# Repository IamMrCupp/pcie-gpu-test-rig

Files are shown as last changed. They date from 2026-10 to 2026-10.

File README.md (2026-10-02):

# pcie-gpu-test-rig

A bench rig for powering a graphics card with no motherboard — a PCIe riser and the card's aux connectors, fed from a current-limited bench supply through a fused, switched, metered 12 V box. Put a dead card on it and in thirty seconds you know whether it draws nothing, idles like a healthy card, or drags the supply into current limit.

Wiring schematic, rev D

## What's here

| Path | What |
|---|---|
| [`wiring/pcie_rig_power.kicad_sch`](wiring/pcie_rig_power.kicad_sch) | The schematic. KiCad 10, ERC clean with every severity on — CI re-checks it on every push. |
| [`wiring/pcie_rig_power.pdf`](wiring/pcie_rig_power.pdf) · [`.svg`](wiring/pcie_rig_power.svg) · [`_bom.csv`](wiring/pcie_rig_power_bom.csv) | Renders and the parts list, all regenerated from the schematic with `kicad-cli`. CI fails if any is stale. |
| [`BOM.md`](BOM.md) | Everything you buy or print, with quantities, dimensions and sources. |
| [`BUILD.md`](BUILD.md) | The procedure: print, fit the panel parts, wire, close, make the leads, the continuity table, first power-up. |
| [`WIRING.md`](WIRING.md) | The electrical reference: wire-by-wire list keyed to the schematic's nets, why the two traps are traps, the lead recipes, limits. |

The printed enclosure — a 4×4 Clickfinity-footed box with the meter, switch, and probe post on the deck and a storage bin on top for the riser kit — lives in [3d-printer-models](https://github.com/IamMrCupp/3d-printer-models) as `pcie-rig-enclosure` ([in review](https://github.com/IamMrCupp/3d-printer-models/pull/165)), so it keeps the shared Gridfinity library and that repo's render checks. The wiring doesn't depend on it.

## How it works

**12 V IN → 8 A fuse → PZEM-031 meter → rocker → outputs.** Keyed XT60 for the riser and the card, banana pairs beside them for probing and plain-lead supplies, and a probe-ground post for the scope. The meter sits ahead of the switch, so you see 12.0 V on the box before you ever enable the card. Every join inside is a WAGO lever nut — no solder, no terminal with two wires on it.

**The protection is the bench supply, not the box.** Set it to 12.0 V, OVP 12.6 V, and a 6 A current limit — the rig's working ceiling. The fuse is a backstop. Everything else in the path is overrated on purpose.

> **Never feed this from an ATX or server supply** — anything that can deliver tens of amps into a shorted card will. A current-limited bench supply is the whole point.

## What it tells you

| Reading | Usual meaning |
|---|---|
| About 0 A | Rails aren't coming up. Check the enable chain, and see *Caveats*. |
| Roughly 1–2.5 A | The card is idling. |
| Supply drops into current limit | A short or a stuck phase. Switch off, then find it with injection and a thermal camera. |

The idle range is a starting point from other people's builds, not a spec. Build your own table from known-good cards.

## Two wiring traps

Both are in [`WIRING.md`](WIRING.md) and on the schematic sheet, and both fail silently:

- **The meter's shunt is in the negative leg**, between its terminals 2 and 1. Land the input negative on the ground bus instead of terminal 2 and the current bypasses the shunt — the meter reads 0.00 A forever and a working card looks dead.
- **The rocker's load and LED pins must not swap.** Put the load on the LED pin and ground on the load pin, and the first flick is a dead short across the meter. Beep the pins before crimping.

## Caveats

- **PERST#.** On a bare riser the PCIe reset line isn't driven by a host. Most cards sequence their rails anyway; not every generation is guaranteed to. If a known-good card sits near 0 A, look there first.
- **This proves a card idles safely and nothing more.** A card that passes still needs a real system and a memory test before it goes back to anyone.

## Prior art

The idea isn't new. northwestrepair's *Super Mega Tester Pro XL* (2023) and GPU Solutions' custom GPU testing power supply (2026) build the same thing; this is my take on it, sized for my bench.

## License

MIT — see [LICENSE](LICENSE). The enclosure in 3d-printer-models is CC BY-NC 4.0.

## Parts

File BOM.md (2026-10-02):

# Bill of materials

Everything you buy or print to build one rig. Quantities are for one box with both outputs fitted. Reference designators match the schematic and [WIRING.md](WIRING.md); the machine-generated list KiCad pulls from the schematic itself is [`wiring/pcie_rig_power_bom.csv`](wiring/pcie_rig_power_bom.csv), and CI fails if the two drift.

Prices move; links are what I bought from. Anything equivalent works if it matches the dimensions in the enclosure's README.

## Panel parts

| Ref | Qty | Part | Notes | Source |
|---|---|---|---|---|
| M1 | 1 | **Peacefair PZEM-031** DC meter, 8–100 V / 0–20 A, LCD, built-in shunt | housing 84.29 × 44.50, bezel 89 × 49, 24.45 deep. Four screw terminals | sold as HiLetgo, [B079JVGRSL](https://www.amazon.com/dp/B079JVGRSL) |
| SW1 | 1 | **Ampper** 20 mm round rocker, 12 V 20 A, 3-pin, illuminated dot | snap-in, body 20.87. Comes in a 10-pack | [B0BZPY5D9L](https://www.amazon.com/dp/B0BZPY5D9L) |
| F1 | 1 | **5×20 mm panel-mount fuse holder**, screw cap | thread 11.6, 26 long. From the fuse kit | Gebildet kit, [B07VT4VRW7](https://www.amazon.com/dp/B07VT4VRW7) |
| — | 1 + spares | **8 A fast-blow 5×20 glass fuse** | from the same kit (steps 5 → 8 A; 5 A blows in normal use) | same |
| J1 | 1 | **AMASS XT60E-M** panel-mount, male, pre-wired 12 AWG | captive nuts in the ears. Body 15.61 × 8.08, flange 27.21 × 12.07, ears 22.60 apart. One spare is handy | Amazon, sold in pairs |
| J3, J4 | 2 | **AMASS XT60E-F** panel-mount, female, pre-wired 12 AWG | loose nuts. Body 18.75 × 11.67, flange 34.25 × 15.85, ears 27.25 apart | same |
| J2, J5 | 2 | **4 mm binding post, red** | thread 7.45, 19 long | uxcell 10-pack (5 colours), [B08LN5T9D7](https://www.amazon.com/dp/B08LN5T9D7) |
| J7, J8, J6 | 3 | **4 mm binding post, black** | same pack | same |

## Joins and terminations

| Ref | Qty | Part | Notes |
|---|---|---|---|
| W1, W2 | 2 | **WAGO 221-415** five-port lever nut | ground bus; switched + bus |
| W3, W4 | 2 | **WAGO 221-413** three-port lever nut | input + join; input − join |
| — | ~1 m each | **14 AWG silicone wire**, red and black | every internal run |
| — | 3 | **6.3 mm insulated female spade**, blue (16–14 AWG) | the rocker's three tabs |
| — | 4 | **ferrules** for 14 AWG | the meter's four screw terminals. WAGOs take bare stranded wire |
| — | 6 | **ring terminals** for an 8 mm stud, 14 AWG | one per post, plus one for the LED return on J8 |
| — | 6 | **M2.5 bolts** | 2 per XT60E. Male: from inside, into its captive nuts. Female: from outside, nut inside |
| — | 4 | **M2.5 nuts** | for J3 and J4 |
| — | — | heat-shrink, 2–4 zip ties | zip ties hold the WAGOs to the base so they don't rattle |

## Leads

Built by you, from stock cables. See *Leads* in [WIRING.md](WIRING.md).

| Qty | Part | For | Source |
|---|---|---|---|
| 3 | **8-pin → 2× 8(6+2) PCIe splitter**, 18 AWG, 22 cm | one for the dual lead, two for the quad lead | Amangny 6-pack, [B094QSRK98](https://www.amazon.com/dp/B094QSRK98) |
| 3 (+1) | **AMASS XT60H male**, with sheath housing | the box end of each lead: dual, quad, riser | Amazon, 5 pairs |
| 1 | **AMASS XT60H female**, with sheath housing | the box end of the bench-supply lead | same pairs |
| 1 short | **12 AWG XT60 pigtail** | the quad lead's splice point | |
| 1 | **4×8-pin → 12VHPWR adapter** | cards with the 16-pin connector | [B0GYHKK5WS](https://www.amazon.com/dp/B0GYHKK5WS) |
| 1 | **PCIe 1x→16x riser kit** (x16 board, x1 card, USB 3.0 lead, SATA → 6-pin) | stores in the bin on the deck; its SATA → 6-pin cord becomes the riser lead | Kingwin, [B07QBF2X6C](https://www.amazon.com/dp/B07QBF2X6C) |

## The box

Printed from [`pcie-rig-enclosure`](https://github.com/IamMrCupp/3d-printer-models/tree/main/pcie-rig-enclosure) in 3d-printer-models. PETG throughout, about 300 g including the coupons.

| Qty | Part | Notes |
|---|---|---|
| 1 | `rig_base` | 142 cm³, feet down |
| 1 | `rig_cup` | 139 cm³, emitted deck-down |
| 1 | `rig_storage_bin` | three bays on the deck: x16 board on edge, x1 card, USB lead. 48 cm³ |
| 1 | `rig_cup_inlay` | optional second colour for the labels |
| 1 each | `deck_coupon`, `meter_fuse_coupon`, `xt60_coupon`, `xt60_ear_ladder`, `joint_coupon` | print-first fit checks — see that README's print order |
| 4 | **M3 × 10** screws | cup to base, self-tapping into printed pilots |
| — | CA glue | the storage bin to the deck |

## Bench

| Qty | Part | Notes |
|---|---|---|
| 1 | **current-limited bench supply**, 12 V, ≥ 6 A | mine is an OWON SPM8104. Set 12.0 V, OVP 12.6 V, 6 A limit. Never an ATX or server supply |
| 1 | DMM with continuity | every check in [BUILD.md](BUILD.md) uses it |

## Tools

Crimper for ferrules and spades, wire stripper, 2 mm hex or #1 Phillips for M2.5, driver for M3, calipers if you change anything.

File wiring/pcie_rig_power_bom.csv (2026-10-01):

Ref | Part | Qty
D1 | LED in SW1 | 1
F1 | 5x20 8 A | 1
J1 | XT60E-M | 1
J2,J5 | post + | 2
J3 | XT60E-F RISER | 1
J4 | XT60E-F CARD | 1
J6 | PROBE GND | 1
J7,J8 | post - | 2
M1 | PZEM-031 | 1
SW1 | rocker | 1
W1,W2 | WAGO 221-415 | 2
W3,W4 | WAGO 221-413 | 2

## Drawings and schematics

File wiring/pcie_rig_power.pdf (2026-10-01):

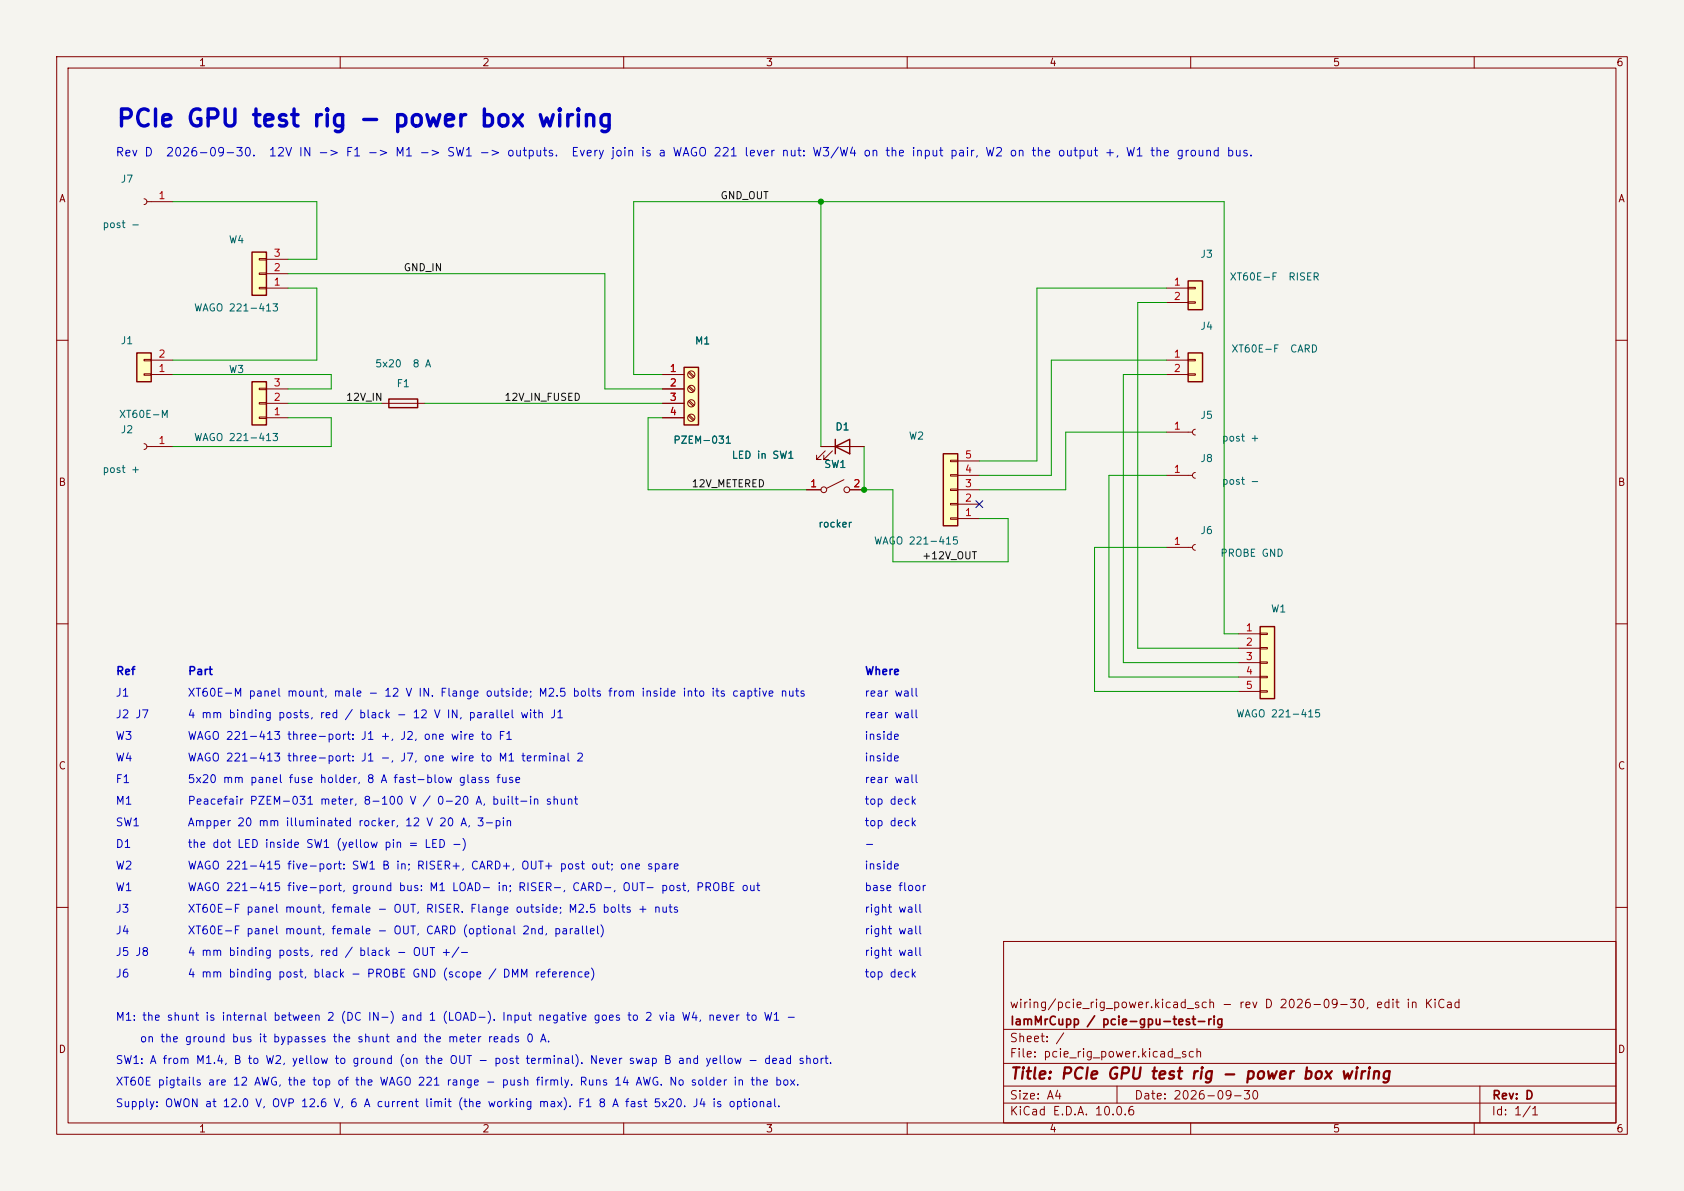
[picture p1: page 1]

on the ground bus it bypasses the shunt and the meter reads 0 A. SW1: A from M1.4, B to W2, yellow to ground (on the OUT - post terminal). Never swap B and yellow - dead short. XT60E pigtails are 12 AWG, the top of the WAGO 221 range - push firmly. Runs 14 AWG. No solder in the box. PCIe GPU test rig - power box wiring

Rev D 2026-09-30. 12V IN -> F1 -> M1 -> SW1 -> outputs. Every join is a WAGO 221 lever nut: W3/W4 on the input pair, W2 on the output +, W1 the ground bus.

top deck XT60E-M panel mount, male - 12 V IN. Flange outside; M2.5 bolts from inside into its captive nuts Ref J1

right wall right wall right wall base floor Part

rear wall
rear wall top deck

4 mm binding posts, red / black - 12 V IN, parallel with J1 WAGO 221-413 three-port: J1 -, J7, one wire to M1 terminal 2 Peacefair PZEM-031 meter, 8-100 V / 0-20 A, built-in shunt WAGO 221-415 five-port: SW1 B in; RISER+, CARD+, OUT+ post out; one spare W4

top deck Supply: OWON at 12.0 V, OVP 12.6 V, 6 A current limit (the working max). F1 8 A fast 5x20. J4 is optional.

5x20 mm panel fuse holder, 8 A fast-blow glass fuse

4 mm binding post, black - PROBE GND (scope / DMM reference) WAGO 221-415 five-port, ground bus: M1 LOAD- in; RISER-, CARD-, OUT- post, PROBE out M1: the shunt is internal between 2 (DC IN-) and 1 (LOAD-). Input negative goes to 2 via W4, never to W1 -

XT60E-F panel mount, female - OUT, RISER. Flange outside; M2.5 bolts + nuts XT60E-F panel mount, female - OUT, CARD (optional 2nd, parallel)

4 mm binding posts, red / black - OUT +/-

wiring/pcie_rig_power.kicad_sch - rev D 2026-09-30, edit in KiCad
IamMrCupp / pcie-gpu-test-rig
Sheet: /
File: pcie_rig_power.kicad_sch
Title: PCIe GPU test rig - power box wiring

Size: A4 | Rev: D
KiCad E.D.A. 10.0.6 | Id: 1/1

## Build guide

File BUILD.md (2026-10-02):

# Build sheet

Start to finish, in order. Parts and quantities are in [BOM.md](BOM.md); the wire-by-wire list and the two traps that fail silently are in [WIRING.md](WIRING.md). Read all three once before you cut anything.

## 1. Print the box

From [`pcie-rig-enclosure`](https://github.com/IamMrCupp/3d-printer-models/tree/main/pcie-rig-enclosure). That README has the print order and the print settings; the short version:

1. **Coupons first.** `deck_coupon`, `meter_fuse_coupon`, `xt60_coupon`, `xt60_ear_ladder`, `joint_coupon` — about 80 g together. Push every panel part into its ladder, bolt an XT60 to each of its cutouts, drop the cup corner over the base corner and run an M3 in. Any hole-to-hole *pitch* you calipered gets a ladder too — the XT60 ears read 0.6 mm long. Anything that doesn't fit changes a constant in `rig_common.scad` before the big parts print.
2. **Base**, feet down, no supports.
3. **Cup**, as emitted (deck on the bed), no supports. Add `rig_cup_inlay` as a second colour if you want filled labels.
4. **Storage bin**, floor down, no supports.

## 2. Fit the panel parts

Dry-fit everything in the bare cup before a single wire goes on. If something binds, fix the print, not the part.

1. **Meter** into the deck cutout from above until its spring clips catch.
2. **Rocker** into its hole from above until it snaps.
3. **Binding posts**: red into J2 (rear) and J5 (right), black into J7 (rear), J8 (right) and J6 (deck). Nut inside, then a ring terminal under a second nut.
4. **Fuse holder** through the rear wall, nut inside. Fuse out for now.
5. **XT60E-M** (J1): flange outside the rear wall, body through, M2.5 bolts from *inside* the box into the connector's captive nuts.
6. **XT60E-F** (J3 RISER, J4 CARD): flange outside the right wall, M2.5 bolts from outside, nuts inside.
7. **Storage bin** onto the back half of the deck with CA, its back edge flush with the deck's back edge. The two empty rectangular pockets under it are left over from an earlier riser dock; ignore them.

## 3. Wire it

Every join is a WAGO 221 lever nut: strip 11 mm, lift the lever, push the wire home, close the lever. Nothing is soldered and no terminal takes two wires. Follow the numbered rows in [WIRING.md](WIRING.md); the groups below are the order that keeps your hands out of your own way.

1. **Input** (rows 1–7). XT60 + pigtail and J2's ring terminal lead into **W3**; one wire from W3 through the fuse holder to the meter's terminal **3**. XT60 − pigtail and J7's lead into **W4**; one wire from W4 to the meter's terminal **2**. Ferrules into the meter.
2. **Meter to switch** (row 8). Terminal **4** to the rocker's **A** tab, spade.
3. **Outputs** (rows 9–12). Rocker **B** tab, spade, to **W2**. From W2 one lever each to the RISER + pigtail, the CARD + pigtail and J5. The fifth port stays empty.
4. **Ground bus** (rows 13–18). Meter terminal **1** into **W1**. From W1 one lever each to the RISER − pigtail, the CARD − pigtail, J8 and J6. The rocker's **yellow** tab goes to J8's terminal, with its own ring, under the same nut.
5. **Dress it.** Zip-tie W1 to the base floor and the other three to the bundle. Leave enough slack that the cup lifts 50 mm off the base without anything pulling.

Before you close it, beep the two traps:

- **Terminal 2 of the meter must not beep to terminal 1.** If it does, the input negative has found the ground bus and the meter will read 0 A forever.
- **The rocker's yellow tab must not beep to A or B**, rocker on or off.

## 4. Close it

Set the cup over the base so its skirt wraps the tongue, and run the four **M3 × 10** screws in from the sides. They self-tap into printed pilots; snug, not tight. Fuse in: **8 A fast-blow**, through the cap on the rear panel.

## 5. Make the leads

From [WIRING.md](WIRING.md) *Leads*: the dual lead from one splitter cable, the quad lead from two, each with a male XT60H on the box end. The bench-supply lead gets a female XT60H. Beep every lead end to end before it touches a card.

## 6. Checks before first power

Nothing plugged into J1, J2 or J7.

| Check | Expect |
|---|---|
| J1 + and J2 to meter terminal 3 | beep, through the fuse |
| J1 − and J7 to meter terminal 2 | beep |
| Meter terminal 2 to terminal 1 | **open** |
| Meter terminal 4 to rocker A | beep |
| Rocker A to every output +, rocker on | beep |
| Rocker A to every output +, rocker off | open |
| Meter terminal 1 to every output −, J8 and J6 | beep |
| Any + to any − | open, rocker on and off |
| Rocker yellow to A or B | open |

Then the first power-up, in this order:

1. Bench supply to **12.0 V, OVP 12.6 V, current limit 0.5 A**. Nothing on the outputs.
2. Plug the supply lead into J1. The meter wakes and reads about 12 V, 0.00 A.
3. Rocker on. The dot lights; every output + reads 12 V to J6.
4. Rocker off. Outputs dead, meter still lit.
5. Raise the current limit to **6 A**. Now, and only now, a lead goes on.

## 7. Use it

Riser board out of the bin, card in the riser, dual lead from RISER to the riser's 6-pin and the card, or the quad lead to CARD for a 16-pin card. Supply on, meter reading 12 V, then the rocker. What the current tells you is in the [README](README.md).

## 8. Service

Four side screws out, cup lifts off with all its wiring intact, base stays latched to the grid. Fuses change from outside through the cap.

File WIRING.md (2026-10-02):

# PCIe test rig — wiring guide

The power box for a bench PCIe GPU test rig: a fused, switched, metered 12 V feed with keyed XT60 outputs for the riser and the card, banana pairs on both ends for probing and for a bench supply with plain leads, and a ground post for your scope or DMM. This is the electrical reference: the wire-by-wire list and the reasons behind it. The procedure is [BUILD.md](BUILD.md), the shopping list is [BOM.md](BOM.md). The schematic it follows is [`wiring/pcie_rig_power.kicad_sch`](wiring/pcie_rig_power.kicad_sch) — open it in KiCad, or read the [PDF](wiring/pcie_rig_power.pdf) / [SVG](wiring/pcie_rig_power.svg). Rev D.

Panel positions, the "cup", and the storage bin refer to the printed enclosure, which lives in the models repo as `pcie-rig-enclosure` ([in review](https://github.com/IamMrCupp/3d-printer-models/pull/165)). The wiring doesn't depend on it — any box that takes a 20 mm rocker, a 5×20 panel fuse holder, 4 mm posts, XT60E panel connectors, and the PZEM-031's 84 × 44 mm cutout will do.

Schematic

**What it is, and isn't.** The source is an OWON bench supply set to **12.0 V, OVP ~12.6 V, current limit 6 A** — the rig's working ceiling, and plenty for watching a card come up without letting a short cook anything. It never carries full boot current. An **8 A** fast-blow fuse on the rear panel is the backstop; the kit goes 5 → 8 A, and 5 would blow in normal use. Everything else in the path is overrated on purpose: 20 A switch, 30 A connectors, 14 AWG wire. This is a diagnostic rig, not a load tester.

## References

What each designator on the sheet is. Quantities, sources and dimensions are in [BOM.md](BOM.md).

| Ref | Part | Where |
|---|---|---|
| **J1** | XT60E-M panel mount, male — 12 V IN. The supply lead ends in a female XT60H | rear wall |
| **J2, J7** | 4 mm binding posts, red / black — 12 V IN, in parallel with J1 | rear wall |
| **W3, W4** | WAGO 221-413 three-port — join the XT60 pigtail and the post on + and on − | inside |
| **F1** | 5×20 mm panel fuse holder, 8 A fast-blow | rear wall |
| **M1** | Peacefair PZEM-031 meter, built-in shunt | top deck |
| **SW1** | Ampper 20 mm illuminated rocker, 3-pin | top deck |
| **D1** | the dot LED inside SW1 — yellow pin is its return | — |
| **W2** | WAGO 221-415 five-port — the switched + bus | inside |
| **W1** | WAGO 221-415 five-port — the ground bus | inside, on the base floor |
| **J3, J4** | XT60E-F panel mount, female — OUT **RISER**, OUT **CARD** (J4 optional, parallel) | right wall |
| **J5, J8** | 4 mm binding posts, red / black — OUT +/− | right wall |
| **J6** | 4 mm binding post, black — PROBE GND | top deck |

## Where things go

| Face | Carries |
|---|---|
| **Top deck** | M1, SW1, J6, and the storage bin |
| **Rear** | J1, J2, J7, F1 — swap a fuse without opening the box |
| **Right** | J3, J4, J5, J8 |
| **Inside** | W1 on the base floor; W2, W3, W4 on their wires |

The top is fixed — service is four screws on the sides and the cup lifts off its base with all its wiring intact. Nothing that carries current is on a part you remove to get at something else.

## Signal path

**12 V IN → F1 → M1 → SW1 → outputs.** The meter sits *ahead* of the switch, so it reads the supply whenever the supply is on; the switch only gates the outputs. That's deliberate: you see 12.0 V on the box before you ever enable the card.

## Wire by wire

Net names match the schematic. All 14 AWG unless noted. Every join is a WAGO 221: nothing in the box is soldered, and no terminal ever takes two wires.

| # | From | To | Net | Notes |
|---|---|---|---|---|
| 1 | J1 **+** pigtail | W3 | `12V_IN` | 12 AWG as supplied |
| 2 | J2 (red post) | W3 | `12V_IN` | |
| 3 | W3 | F1, either end | `12V_IN` | the one wire into the fuse |
| 4 | F1, other end | M1 terminal **3** — DC IN + | `12V_IN_FUSED` | ferrule |
| 5 | J1 **−** pigtail | W4 | `GND_IN` | |
| 6 | J7 (black post) | W4 | `GND_IN` | |
| 7 | W4 | M1 terminal **2** — DC IN − | `GND_IN` | **Not W1** — see below |
| 8 | M1 terminal **4** — LOAD + | SW1 **A** (power) | `12V_METERED` | spade |
| 9 | SW1 **B** (load) | W2 | `+12V_OUT` | spade on the tab, lever nut on the other end |
| 10 | W2 | J3 **+** pigtail | `+12V_OUT` | RISER |
| 11 | W2 | J4 **+** pigtail | `+12V_OUT` | CARD |
| 12 | W2 | J5 (red post) | `+12V_OUT` | the fifth port stays spare |
| 13 | M1 terminal **1** — LOAD − | W1 | `GND_OUT` | the ground bus starts here |
| 14 | W1 | J3 **−** pigtail | `GND_OUT` | RISER |
| 15 | W1 | J4 **−** pigtail | `GND_OUT` | CARD |
| 16 | W1 | J8 (black post) | `GND_OUT` | |
| 17 | W1 | J6 (probe post) | `GND_OUT` | |
| 18 | SW1 **yellow** (LED −) | J8's terminal | `GND_OUT` | 18 AWG is fine; it shares the OUT − post's ring terminal |

**PZEM-031 terminals**, top to bottom as printed on its back: **1 LOAD −, 2 DC IN −, 3 DC IN +, 4 LOAD +.** The + side passes straight through 3 → 4; the shunt sits between 2 and 1.

**Why the input negative gets its own lever nut and never touches W1.** The meter measures current as the drop across its internal shunt, which is in the negative leg between terminals 2 and 1. Land the input negative on the ground bus and the current bypasses the shunt: the meter reads 0.00 A forever and the rig looks dead when it isn't. Input − goes through W4 to terminal 2, the bus hangs off terminal 1, and the probe post — J6 — is on that bus, so a scope reference sees exactly what the card sees.

**Why the rocker's B and yellow must never swap.** A = supply, B = load, yellow = LED return to ground. Put the load wire on yellow and ground on B and the first flick of the switch is a dead short across the meter. Beep the three pins in continuity mode before you crimp: A–B closes when the rocker is on, yellow never closes to either.

## Leads (you build these; they live in a parts drawer)

All from the six-pack of 6+2 dual-output PCIe cords. Cut the PSU-side 8-pin off each and put a **male XT60H** (AMASS, with the sheath housing) on the cut end: yellows to +, blacks to −.

- **Dual lead.** One cord → XT60H → 2 × 8(6+2). Feeds the riser's 6-pin (leave the +2 tail off) and one card connector, or two card connectors.
- **Quad lead.** Two cords → 4 × 8-pin, for the 4×8-pin → 12VHPWR adapter. Twelve 18 AWG wires won't go in one XT60 solder cup — splice them to a short **12 AWG XT60 pigtail** instead, heat-shrunk.
- **Riser lead.** The riser kit's own SATA → 6-pin cord. Cut the SATA plug off — it's the weak point on these adapters, about 4.5 A across its three 12 V pins — and solder a male XT60H to the cut end. Mine has 2 yellow and 4 black: twist and tin each group, yellows into +, all four blacks into − (one black is the 6-pin's sense line, tied to ground). Four 18 AWG blacks are about the size of the cup; if they won't seat, butt-splice them to a short 14 AWG tail first. Any red or orange wire is 5 V / 3.3 V from the SATA side: cut it back and insulate it. Sheath on the wire before you solder.

Beep every lead end-to-end before it touches a card: + to every yellow pin, − to every black, nothing between.

## Building it

The procedure — fitting, wiring order, the continuity table and the first power-up — is [BUILD.md](BUILD.md).

## Limits

- **6 A working limit**, set at the supply. Fuse at 8 A fast-blow. Never above the meter's 20 A.
- The meter needs ≥ 8 V to run. Below that it goes dark; the rig still passes power.
- Everything downstream of an XT60 runs on the lead's 18 AWG yellows. Fine at 6 A. Fine at 20. Not at 30.
- If the rig is ever fed from something other than the OWON, add a reverse-polarity module on the input first. XT60 is keyed; banana posts are not.

## Files

- [`wiring/pcie_rig_power.kicad_sch`](wiring/pcie_rig_power.kicad_sch) — KiCad 10 schematic, the source. ERC clean with every severity on.
- [`wiring/pcie_rig_power.pdf`](wiring/pcie_rig_power.pdf), [`wiring/pcie_rig_power.svg`](wiring/pcie_rig_power.svg) — renders. Regenerate with `kicad-cli sch export pdf` / `svg`.
- [`wiring/pcie_rig_power_bom.csv`](wiring/pcie_rig_power_bom.csv) — the parts list KiCad extracts from the schematic, grouped by value. Regenerate with `kicad-cli sch export bom`; CI checks it matches.

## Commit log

2026-09-29 feat: rev C wiring for the PCIe GPU test rig power box, moved from 3d-printer-models
    [pcie_rig_power.kicad_sch]
2026-09-29 fix(ci): run the kicad container as root so checkout can write
2026-09-29 fix(ci): use the full kicad image so the symbol libraries resolve
2026-09-29 fix(ci): attach renders as an artifact instead of byte-comparing them
2026-10-01 feat(wiring): rev D — WAGO 221 lever nuts join the input pair (W3/W4), the switched + bus (W2) and the ground bus (W1); no two wires on one terminal
    [pcie_rig_power.kicad_sch]
2026-10-01 docs: split into BOM.md, BUILD.md and a reference WIRING.md; KiCad-exported BOM checked in CI; posts renumbered J2/J7/J5/J8
    [pcie_rig_power.kicad_sch, pcie_rig_power_bom.csv]
2026-10-02 docs: storage bin replaces the riser dock; riser lead built from the kit's SATA → 6-pin cord
